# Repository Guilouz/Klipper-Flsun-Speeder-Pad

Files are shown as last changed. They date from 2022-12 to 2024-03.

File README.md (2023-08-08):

 # FLSUN Speeder Pad Configurations

Sans titre-2 copie

<br />

## About

This guide explains the whole process in order to obtain Root access on the Speeder Pad, to configure it correctly with official Klipper builds and optimized printer settings.

By default, FLSUN does not use builds from official GitHub repositories. Updates point to Gitee repositories which are very slow, sometimes inaccessible and not updated.
In addition, during Delta Calibration, tower angles and delta radius are never recalculated in their Klipper build, which can cause several issues.

This settings are compatible with FLSUN Speeder Pad.

- Useful and automated macros with notifications to KlipperScreen
- Improved configurations
- Configurations for many ADXL
- And more...

<br />

Before using Klipper please read this documentations:

- Klipper (Operating System): https://www.klipper3d.org/
- Moonraker (API Web Server): https://moonraker.readthedocs.io/
- Mainsail (Web Interface): https://docs.mainsail.xyz/
- KlipperScreen (Screen Interface): https://klipperscreen.readthedocs.io/

<br />

If you like my work, don't hesitate to support me by paying me a 🍺 or a ☕. Thank you 🙂

Donate (https://ko-fi.com/guilouz)

<br />

## Wiki

Guide is now available here: https://github.com/Guilouz/Klipper-Flsun-Speeder-Pad/wiki

<br />

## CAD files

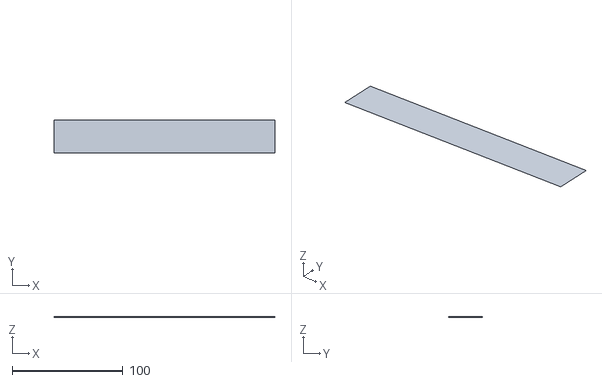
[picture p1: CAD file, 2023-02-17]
Downloads/First_Layer_Test.stl
200.0 x 30.0 x 0.2

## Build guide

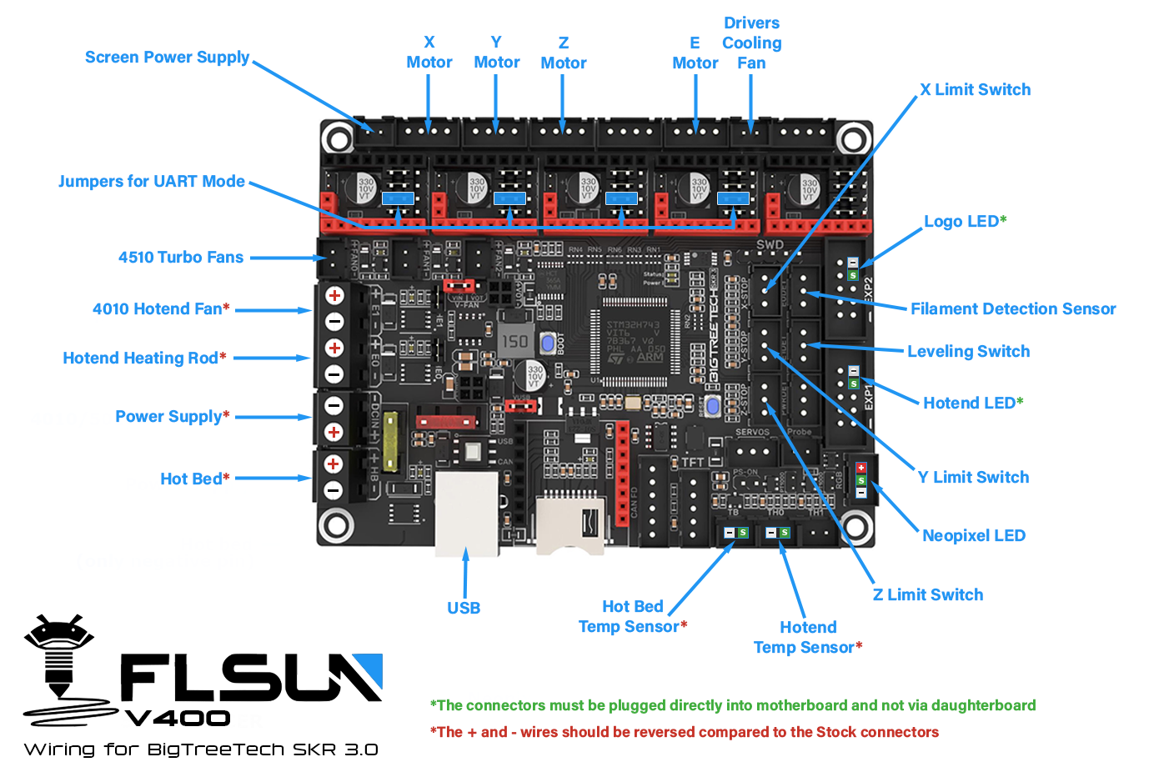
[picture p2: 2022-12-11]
Configurations/FLSUN V400/FLSUN V400 - BigTreeTech SKR 3.0 Wiring.png

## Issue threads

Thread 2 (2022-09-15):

Root via update.sh still work?

arraylabs, 2022-09-15:
I'm not having any luck with the update.sh appearing to do anything. Does this method still work with recently delivered printers/speederpads?

Guilouz, 2022-09-15:
Just fixed this. Re-download zip file.

arraylabs, 2022-09-15:
Thanks, unfortunately it still doesn't appear to do anything. I'm unable to log into the pad with the provided username and password. I also don't see the .over file on the USB after booting the pad with the stick inserted which kinda implies the update.sh script isn't getting run.

Guilouz, 2022-09-15:
Try to re-download new zip, it have been updated to set password for pi user to flsun.

arraylabs, 2022-09-16:
Sorry to say but still no luck. I appreciate your time trying to sort it out.

arraylabs, 2022-09-16:
Just to confirm where the directions say "root folder" that should be the same level as the cura 4 & 5 installation files, correct?

Guilouz, 2022-09-16:
Not understand what you mean with Cura.

Root Acess is needed to change time zone, wifi location, klipper etc in SSH, nothing to see with Cura.

jFensch, 2022-09-16:
I am also experiencing the issue:
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

Guilouz, 2022-09-16:
It seems Flsun have changed something to block root access.

Brubrui, 2022-10-03:
At night, does the password seem to have changed because flsun is not giving access to the spider pad? Do you know anything about it?. thank you

Closed 2022-09-15.

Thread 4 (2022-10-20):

Erreur mise à jour Klipperscreen si multi instances Klipper

ManuMod, 2022-10-20:
Après la modif de moonraker.conf (en PJ), le Hard recovery retourne l'erreur "Repo has not been verified, clone aborted".
[moonraker.conf.txt](https://github.com/Guilouz/Klipper-Flsun-Speeder-Pad/files/9834097/moonraker.conf.txt)

ManuMod, 2022-10-20:
J'ai suivi la procédure avec 3 instances.

Guilouz, 2022-10-20:
Suis la procédure avec une seule instance, il y a des problèmes de compatibilités avec les nouveaux chemins de moonraker changés récemment.

ManuMod, 2022-10-20:
OK, merci pour l'info.
Je voulais conserver la fonctionnalité pour plus tard, mais je peux effectivement débuter Klipper avec 1 instance et refaire une install si je trouve plus stable en multi instances. Tu envisages également de l'utiliser en multi instances ?

Guilouz, 2022-10-20:
Non c’est juste un pad de test, j’en ai un autre avec ma V400

ManuMod, 2022-10-22:
Pour l'info, j'ai eu la même erreur avec 1 seule instance de Klipper, mais qui a été résolu après une mise à jour de Moonraker.

Guilouz, 2022-10-22:
Oui il y a eu des updates aujourd'hui pour Moonraker et notamment un correctif pour le multi instance.

ManuMod, 2022-10-22:
Effectivement, j'ai vu ton issue sur le sujet.
Je ne sais pas s'il y a un rapport avec les màj de Moonraker, mais j'ai également eu 1 erreur avec le service WebcamHD qui restait en état Failed. Ce que j'ai résolu à coup de plugin mainsail/crowsnest.

Guilouz, 2022-10-22:
J’étais pas sûr que crownest fonctionnait correctement sous Ubuntu. Pas de problème avec? La configuration de la cam avec le fichier de conf fonctionne ?

ManuMod, 2022-10-22:
Cela fonctionne tip top avec ma C310. J'ai repris la config par défaut en modifiant seulement la résolution pour 720HD. Aucune erreur à l'install par contre l'ajout auto de l'update n'écrit pas les lignes dans monraker.conf. Faut penser à les ajouter.

Closed 2022-10-20.

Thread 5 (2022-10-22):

Utiliser gcode sur clef USB

ManuMod, 2022-10-22:
Même si l'envoi direct du gcode sur Mainsail est l'utilisation principale, je souhaiterai pouvoir conserver la fonctionnalité de lecture des gcodes sur clef USB.

Le montage de la clef USB n'est pas automatique et une fois montée en SSH, elle n'est pas reconnue dans Mainsaill.

Faut-il mettre en place qq chose du style autofs ou script, associé à un symlink sur 1 dossier dédié dans pi/gcodes_files ?

Guilouz, 2022-10-22:
C’est pas le but de Klipper de print via clé USB ou microSD. C’est bien pour cette raison que ce n’est pas une fonctionnalité de Mainsail.
Il me semble que l’USB est monté uniquement au démarrage si une clé usb est insérée.
Je t’avouerais que je n’ai pas testé, j’envoie tous mes gcode depuis Cura directement sur le pad et ensuite je lance l’impression depuis le pad.

ManuMod, 2022-10-22:
Dsl, effectivement la clef est correctement montée au démarrage et même à chaud, mais dans /pi/gcode_files/USB-Disk alors que Mainsaill utilise /printer_data/gcodes.

Guilouz, 2022-10-22:
Merci de l'info, je vais rajouté ça au tuto.

ManuMod, 2022-10-22:
Je pense qu'il serait plus propre de faire un symlink sur les dossiers gcode uniquement et cela permettrai pour le mode 3 instances (que je compte toujours essayer) de faire un symlink par printer_data sur le même dossier gcodes. Plus simple si une seule et même base de gcode, non?

Guilouz, 2022-10-22:
Oui ça peut être réalisable avec:

ln -s /home/pi/gcode_files/USB-Disk /home/pi/printer_data_1/gcodes/USB-Disk
ln -s /home/pi/gcode_files/USB-Disk /home/pi/printer_data_2/gcodes/USB-Disk
ln -s /home/pi/gcode_files/USB-Disk /home/pi/printer_data_3/gcodes/USB-Disk

J'ai pas encore vraiment poussé les recherches avec plusieurs instances.

ManuMod, 2022-10-22:
Effectivement ce serait LA méthode pour 3 instances.

Ce que j'évoquais était plutôt de limiter le symlink au /home/pi/gcode_files/, mais après mûre réflexion (ou plutôt 1 peu de repos ;-), c'est une bêtise pour les 3 instances, au vue des config dédiées aux imprimantes et/ou PLA.

Guilouz, 2022-10-22:
Oui car chaque imprimante est différente et n’utilisent pas forcément toutes les mêmes gcodes.
Il est préférable d’avoir pour chacunes d’elles leurs dossiers gcode.

Closed 2022-10-22.

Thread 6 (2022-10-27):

Timelapse pour 3 instances de Klipper

ManuMod, 2022-10-27:
Salut,

L'installateur de Timelapse ne gère pas le multi-instance de Klipper. Du coup, cela se passe manuellement sous SSH. source https://github.com/mainsail-crew/moonraker-timelapse/issues/13

Exemple pour 3 instances de Klipper :

```
cd ~/
git clone https://github.com/mainsail-crew/moonraker-timelapse.git
ln -sf "/home/pi/moonraker-timelapse/component/timelapse.py" "/home/pi/moonraker/moonraker/components/timelapse.py"
ln -sf "/home/pi/moonraker-timelapse/klipper_macro/timelapse.cfg" "/home/pi/printer_1_data/config/timelapse.cfg"
ln -sf "/home/pi/moonraker-timelapse/klipper_macro/timelapse.cfg" "/home/pi/printer_2_data/config/timelapse.cfg"
ln -sf "/home/pi/moonraker-timelapse/klipper_macro/timelapse.cfg" "/home/pi/printer_3_data/config/timelapse.cfg"
sudo reboot
```

:warning: Ne pas oublier d'ajouter [timelapse] dans le fichier Moonraker.conf, ainsi que les lignes pour l'update.

Si le service WebcamHD ne fonctionne pas (comme moi :smile:) , possible d’utiliser le plugin de Mainsall : https://github.com/mainsail-crew/crowsnest

Guilouz, 2022-10-27:
Bien vu, j'utilise pas les timelapse alors je me suis pas penché dessus.

Guilouz, 2022-10-27:
J'ai déjà reporté l'issue ici : https://github.com/mainsail-crew/moonraker-timelapse/issues/71

Closed 2022-10-27.

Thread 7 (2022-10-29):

Keyboard missing some typo ...

themacboy, 2022-10-29:
After update the board I tryed to connect to my network but ... when I type my passwords I can't set some symbol.

Thats symbol is used on my network pass, and I can't change it due I had more than 30 perophericals connected to this network.

Any idea?

themacboy, 2022-10-29:
Finally I just connected a external keyboard.

Closed 2022-10-29.

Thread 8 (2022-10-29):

ADXL345 issue ...

themacboy, 2022-10-29:
Excuse me, I doubt this is a problem with your config. But I will try to ask for help.

After running the TEST_RESONANCES AXIS=X, I get always this error:

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

Any idea? Is this speeder pad to weak?

themacboy, 2022-10-29:
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

Ummm xorg? why is this process running and having too much CPU load? lol

themacboy, 2022-10-29:
I just used:

sudo service KlipperScreen stop

to stop Xorg, but the problem still happens!

themacboy, 2022-10-29:
Solved !

I have reduced microsteps from 128 to 32.

Too much data load to run a resonance test !

Guilouz, 2022-10-29:
Working fine for me with 128 microsteps. I have doing many tests for that without issue.

themacboy, 2022-10-30:
Can you share the actual specs of your Speeder Pad? I like to compare with mine to check for different hardware versions.

Thanks in advance!

Guilouz, 2022-10-30:
description: Computer
    product: sun50iw10
    width: 32 bits
    capabilities: smp
  *-core
       description: Motherboard
       physical id: 0
     *-cpu:0
          description: CPU
          product: cpu
          physical id: 0
          bus info: cpu@0
          size: 1512MHz
          capacity: 1512MHz
          capabilities: fp asimd aes pmull sha1 sha2 crc32 cpufreq
     *-cpu:1
          description: CPU
          product: cpu
          physical id: 1
          bus info: cpu@1
          size: 1512MHz
          capacity: 1512MHz
          capabilities: fp asimd aes pmull sha1 sha2 crc32 cpufreq
     *-cpu:2
          description: CPU
          product: cpu
          physical id: 2
          bus info: cpu@2
          size: 1512MHz
          capacity: 1512MHz
          capabilities: fp asimd aes pmull sha1 sha2 crc32 cpufreq
     *-cpu:3
          description: CPU
          product: cpu
          physical id: 3
          bus info: cpu@3
          size: 1512MHz
          capacity: 1512MHz
          capabilities: fp asimd aes pmull sha1 sha2 crc32 cpufreq
     *-cpu:4 DISABLED
          description: CPU
          product: idle-states
          physical id: 4
          bus info: cpu@4
     *-memory
          description: System memory
          physical id: 5
          size: 976MiB
  *-usbhost:0
       product: SW USB2.0 'Enhanced' Host Controller (EHCI) Driver
       vendor: Linux 4.9.191 ehci_hcd
       physical id: 1
       bus info: usb@1
       logical name: usb1
       version: 4.09
       capabilities: usb-2.00
       configuration: driver=hub slots=1 speed=480Mbit/s
     *-usb
          description: USB hub
          product: USB2.0 Hub
          vendor: Genesys Logic, Inc.
          physical id: 1
          bus info: usb@1:1
          version: 85.38
          capabilities: usb-2.00
          configuration: driver=hub maxpower=100mA slots=4 speed=480Mbit/s
        *-usb
             description: USB hub
             product: USB2.0 Hub
             vendor: Genesys Logic, Inc.
             physical id: 1
             bus info: usb@1:1.1
             version: 85.38
             capabilities: usb-2.00
             configuration: driver=hub maxpower=100mA slots=4 speed=480Mbit/s
           *-usb
                description: Generic USB device
                product: USB 10/100 LAN
                vendor: Realtek
                physical id: 2
                bus info: usb@1:1.1.2
                version: 20.00
                serial: 000000000000
                capabilities: usb-2.10
                configuration: driver=r8152 maxpower=100mA speed=480Mbit/s
  *-usbhost:1
       product: SW USB2.0 'Open' Host Controller (OHCI) Driver
       vendor: Linux 4.9.191 ohci_hcd
       physical id: 2
       bus info: usb@2
       logical name: usb2
       version: 4.09
       capabilities: usb-1.10
       configuration: driver=hub slots=1 speed=12Mbit/s
  *-mmc0
       description: MMC Host
       physical id: 3
       logical name: mmc0
     *-device
          description: SD/MMC Device
          product: AJTD4R
          vendor: Unknown (21)
          physical id: 0
          logical name: /dev/mmcblk0
          date: 07/2022
          serial: 4152223877
          size: 15634268160
          capabilities: mmc gpt-1.00 partitioned partitioned:gpt
          configuration: guid=ab6f3888-569a-4926-9668-80941dcb40bc logicalsectorsize=512 sectorsize=512
        *-volume:0
             description: Windows FAT volume
             physical id: 1
             logical name: /dev/mmcblk0p1
             version: FAT16
             serial: 0000-0000
             size: 15EiB
             capabilities: nomount fat initialized
             configuration: FATs=2 filesystem=fat label=Volumn name=boot-resource
        *-volume:1
             description: data partition
             vendor: Windows
             physical id: 2
             logical name: /dev/mmcblk0p2
             serial: a0085546-4166-744a-a353-fca9272b8e46
             capacity: 511KiB
             capabilities: nomount
             configuration: name=env
        *-volume:2
             description: data partition
             vendor: Windows
             physical id: 3
             logical name: /dev/mmcblk0p3
             serial: a0085546-4166-744a-a353-fca9272b8e47
             capacity: 511KiB
             capabilities: nomount
             configuration: name=env-redund
        *-volume:3
             description: data partition
             vendor: Windows
             physical id: 4
             logical name: /dev/mmcblk0p4
             serial: a0085546-4166-744a-a353-fca9272b8e48
             capacity: 14MiB
             capabilities: nomount
             configuration: name=boot
        *-volume:4
             description: EXT4 volume
             vendor: Linux
             physical id: 5
             logical name: /dev/mmcblk0p5
             version: 1.0
             serial: dff38665-5375-4b5a-b230-cb6e7966bc49
             size: 14GiB
             capacity: 14GiB
             capabilities: nomount journaled extended_attributes large_files huge_files dir_nlink recover 64bit extents ext4 ext2 initialized
             configuration: created=2022-09-09 05:32:23 filesystem=ext4 label=rootfs lastmountpoint=/ modified=1970-01-01 01:00:07 mounted=1970-01-01 01:00:07 name=rootfs state=clean
        *-volume:5
             description: data partition
             vendor: Windows
             physical id: 6
             logical name: /dev/mmcblk0p6
             serial: a0085546-4166-744a-a353-fca9272b8e4a
             capacity: 4095KiB
             capabilities: nomount
             configuration: name=rootfs_data
        *-volume:6
             description: data partition
             vendor: Windows
             physical id: 7
             logical name: /dev/mmcblk0p7
             serial: a0085546-4166-744a-a353-fca9272b8e4b
             capacity: 511KiB
             capabilities: nomount
             configuration: name=private
        *-volume:7
             description: data partition
             vendor: Windows
             physical id: 8
             logical name: /dev/mmcblk0p8
             serial: a0085546-4166-744a-a353-fca9272b8e4c
             capacity: 15MiB
             capabilities: nomount
             configuration: name=recovery
        *-volume:8
             description: data partition
             vendor: Windows
             physical id: 9
             logical name: /dev/mmcblk0p9
             serial: a0085546-4166-744a-a353-fca9272b8e4d
             capacity: 511KiB
             capabilities: nomount
             configuration: name=UDISK
  *-mmc1
       description: MMC Host
       physical id: 4
       logical name: mmc1
  *-mmc2
       description: MMC Host
       physical id: 5
       logical name: mmc2
     *-device
          description: SDIO Device
          physical id: 0
          bus info: mmc@2:0001
          serial: 0
          capabilities: sdio
        *-interface:0
             product: 43430
             vendor: Broadcom
             physical id: 1
             bus info: mmc@2:0001:1
             logical name: mmc2:0001:1
        *-interface:1
             product: 43430
             vendor: Broadcom
             physical id: 2
             bus info: mmc@2:0001:2
             logical name: mmc2:0001:2
  *-sound
       description: audiocodec
       physical id: 6
       logical name: card0
       logical name: /dev/snd/controlC0
       logical name: /dev/snd/pcmC0D0c
       logical name: /dev/snd/pcmC0D0p
  *-graphics
       physical id: 7
       logical name: /dev/fb0
       capabilities: fb
       configuration: depth=32 resolution=1024,600
  *-input:0
       product: sunxi-keyboard
       physical id: 8
       logical name: input0
       logical name: /dev/input/event0
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
themacboy, 2022-10-31:
Looks similar :( hahaha

Thx

fzechert, 2022-11-08:
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

Thanks, this worked for me as well, I used 64 microsteps in the configuration file.
After the calibration is done, I can set microsteps back to 128 right? Only a problem during the calibration.

Guilouz, 2022-11-08:
I have no issue with adxl and 128 microsteps.
No you must use settings you have used while Resonance testing

themacboy, 2022-11-08:
> I have no issue with adxl and 128 microsteps. No you must use settings you have used while Resonance testing

listen people! ;) lot of them having this issue while doing resonance check or while printing too.

Guilouz, 2022-11-08:
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

I have 2 pad, one V400 pad on Ubuntu 20.04 LTS and one standalone pad on Ubuntu 22.04 LTS, I tested them both with resonance tests up to 130 Hz without problem (with rpi pico and pis module) and printed an object older than 17h.

I don't understand what's affecting this in both of you but it works well in other people as well.
However nothing prevents you from using 16 microsteps if you want ;) More steps potentially means a more precise machine.

themacboy, 2022-11-08:
> I don't understand what's affecting this in both of you but it works well in other people as well. However nothing prevents you from using 16 microsteps if you want ;) More steps potentially means a more precise machine.

I don't understand it either.

I personally lowered it to 32, and now it works fine.
Really, just a 3D printer we don't need this high precision and loss of torque

fzechert, 2022-11-09:
Thanks for your help and hints. Here is my solution that I managed to get working (kind of). If somebody stumbles upon this issue in the future, it might help.

Unfortunately, I did not have another Microcontroller that is compatible with Klipper other than the PI Zero. So my solution now was to set up Klipper completely on a Raspberry PI 4B 4GB, and not using the Speeder Pad from FLSUN.

This makes it possible to connect the ADXL to the GPIO PINs of the Raspberry PI directly, without the need of an intermediate Pi Zero. Configuration for this can be found in the Klipper Manual: https://www.klipper3d.org/Measuring_Resonances.html and https://www.klipper3d.org/RPi_microcontroller.html

Even with the Raspberry PI 4B 4GB I was not able to complete the SAHPER_CALIBRATE command successfully. It worked for the X Axis but the Y Axis failed at 124 Hz (with 128 micro steps). But since the test normally ends at 133 Hz, which is not so far from 124 Hz, I figured this is good enough.

So I ran the following commands in Klipper:

```
SHAPER_CALIBRATE AXIS=x
SHAPER_CALIBRATE AXIS=y FREQ_END=123
```

This worked fine and I got the following results:

```
[input_shaper]
shaper_type_x = mzv
shaper_freq_x = 53.4
shaper_type_y = mzv
shaper_freq_y = 56.2
```

Then I disconnected the Raspberry PI and connected again with the Speeder Pad. Just Copy those configurations to the `printer.cfg` in the SpeedPad, and done.

I still don't know why we have so many problems with the input shaper. But this is good enough for me now.

If anybody has an Idea on how to trouble shoot this further and find / fix the underlying problem, let me know. I will be glad to help in troubleshooting. But until then, I am out of ideas as well.

:smile:

Closed 2022-10-29.

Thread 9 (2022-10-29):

Web Cam not working

Naninani, 2022-10-29:
Thx for putting together this guide! I just got my v400 and update it using your repo.

The issue with the web cam is that it is not initialized. It was working perfectly fine with the stock pad and firmware, but stopped after the update.

Some findings.
1. `usbutils` is not installed by default. I had to install it in order to list the attached devices.
    ```
     $ lsusb
     -bash: lsusb: command not found
    ```

    ```
    $ sudo apt-get install usbutils
    ```

1. `lsusb` shows the camera and it recognized by the system.
    ```
    $ lsusb
    Bus 002 Device 001: ID 1d6b:0001 Linux Foundation 1.1 root hub
    Bus 001 Device 004: ID 1a86:7523 QinHeng Electronics HL-340 USB-Serial adapter
    Bus 001 Device 006: ID 046d:0843 Logitech, Inc. Webcam C930e
    Bus 001 Device 005: ID 0bda:8152 Realtek Semiconductor Corp. RTL8152 Fast Ethernet Adapter
    Bus 001 Device 003: ID 05e3:0608 Genesys Logic, Inc. Hub
    Bus 001 Device 002: ID 05e3:0608 Genesys Logic, Inc. Hub
    Bus 001 Device 001: ID 1d6b:0002 Linux Foundation 2.0 root hub
    ```

1. However its not initialized
    ```
    $ dmesg | grep -i "Camera"
    [   11.303638] uvcvideo 1-1.3:1.0: Entity type for entity Camera 1 was not initialized!
    [  360.264708] uvcvideo 1-1.3:1.0: Entity type for entity Camera 1 was not initialized!
    ```

    ```
    $ ls -ltrh /dev/video*
    crw-rw---- 1 root video 81, 0 Oct 29 02:32 /dev/video0
    ```

    ```
    sudo lsusb -t
    /:  Bus 02.Port 1: Dev 1, Class=root_hub, Driver=sunxi-ohci/1p, 12M
    /:  Bus 01.Port 1: Dev 1, Class=root_hub, Driver=sunxi-ehci/1p, 480M
        |__ Port 1: Dev 2, If 0, Class=Hub, Driver=hub/4p, 480M
            |__ Port 1: Dev 3, If 0, Class=Hub, Driver=hub/4p, 480M
                |__ Port 2: Dev 5, If 0, Class=Vendor Specific Class, Driver=r8152, 480M
            |__ Port 3: Dev 4, If 0, Class=Video, Driver=uvcvideo, 480M
            |__ Port 3: Dev 4, If 1, Class=Video, Driver=uvcvideo, 480M
            |__ Port 3: Dev 4, If 2, Class=Audio, Driver=, 480M
            |__ Port 3: Dev 4, If 3, Class=Audio, Driver=, 480M
            |__ Port 4: Dev 6, If 0, Class=Vendor Specific Class, Driver=ch341, 12M
    ```

Guilouz, 2022-10-29:
Check my github to use Crowsnest

Closed 2022-10-29.

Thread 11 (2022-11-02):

Update docs

piwi3910, 2022-11-02:
Please update the docs, to reflect the V400 motherboard needs a max 8GB sdcard, with bigger ones, you will not be able to format it correctly.

themacboy, 2022-11-02:
Are you sure? I only own 16gb micro sd cards, and remember that I have updated my MKS Robin nano V.2 a few times.

But not totally sure now.

piwi3910, 2022-11-02:
I'm sure a 32GB doesn't work, tried multiple
Tried it with a 4 and 8 an both work. 16 I didn't try as I didn't have any

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

Guilouz, 2022-11-03:
I can flash my V400 with my 16Gb or 32Gb microSD without issue.

fzechert, 2022-11-06:
I can confirm this issue with my V400 printer. Flashing the SpeederPad worked with 32GB / 64GB micro SD card. Flashing the Robin_nano35.bin firmware to the board installed in the top of the printer did not work with 32GB / 64GB micro SD card. I had an old 64MB SD-Card with a SD to micro SD adapter that worked fine.

Maybe just add a hint, if the flashing does not work, use a <= 16GB SD Card.

Anyway, thanks for this great manual and your effort @Guilouz

Closed 2022-11-03.

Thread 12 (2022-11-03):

crowsnest install docs incomplete

piwi3910, 2022-11-03:
There are some steps missing for crowsnest

1) the default crowsnest service looks for the config file at /home/pi/klipper_config/crowsnest.conf
This means that the template that you copy over in your step:

"cp /home/pi/crowsnest/sample_configs/mainsail_default.conf /home/pi/printer_data/config/crowsnest.conf"
is not loaded

as you can see from this log:

[11/03/22 08:43:33] crowsnest: Version Control: ffmpeg is up to date. (4.2.7-0ubuntu0.1)
[11/03/22 08:43:33] crowsnest: INFO: Print Configfile: '/home/pi/klipper_config/crowsnest.conf'
[11/03/22 08:43:33] crowsnest:          [crowsnest]
[11/03/22 08:43:33] crowsnest:          log_path: ~/klipper_logs/crowsnest.log
[11/03/22 08:43:33] crowsnest:          log_level: verbose
[11/03/22 08:43:33] crowsnest:          delete_log: false
[11/03/22 08:43:33] crowsnest:
[11/03/22 08:43:33] crowsnest:          [cam 1]
[11/03/22 08:43:33] crowsnest:          mode: mjpg
[11/03/22 08:43:33] crowsnest:          port: 8080
[11/03/22 08:43:34] crowsnest:          device: /dev/video0
[11/03/22 08:43:34] crowsnest:          resolution: 640x480
[11/03/22 08:43:34] crowsnest:          max_fps: 15

the fix is:

sudo nano /etc/systemd/system/crowsnest.service
 change the line Environment to reflect the right path
Environment=CROWSNEST_CONFIG=/home/pi/printer_data/config/crowsnest.conf
systemctl daemon-reload
and restart your crowsnest service from mainsail or systemd
rm -rf /home/pi/klipper_config

then logs show correct:

[11/03/22 08:47:44] crowsnest: Version Control: ffmpeg is up to date. (4.2.7-0ubuntu0.1)
[11/03/22 08:47:44] crowsnest: INFO: Print Configfile: '/home/pi/printer_data/config/crowsnest.conf'
[11/03/22 08:47:44] crowsnest:          [crowsnest]
[11/03/22 08:47:44] crowsnest:          log_path: ~/klipper_logs/crowsnest.log
[11/03/22 08:47:44] crowsnest:          log_level: verbose
[11/03/22 08:47:44] crowsnest:          delete_log: false
[11/03/22 08:47:44] crowsnest:
[11/03/22 08:47:44] crowsnest:          [cam 1]
[11/03/22 08:47:44] crowsnest:          mode: mjpg
[11/03/22 08:47:44] crowsnest:          port: 8080
[11/03/22 08:47:44] crowsnest:          device: /dev/video0
[11/03/22 08:47:44] crowsnest:          resolution: 1920x1080
[11/03/22 08:47:44] crowsnest:          max_fps: 25
[11/03/22 08:47:44] crowsnest:          v4l2ctl: focus_auto=0,focus_absolute=50,zoom_absolute=100,exposure_auto_priority=0,exposure_auto=1,exposure_absolute=500,brightness=150,contrast=128,saturation=128,sharpness=128,white_balance_temperature_auto=0,white_balance_temperature=3250

now if you run 3 instances: copying over the template file 3 times doesn't seem to work well.
as crowsnest only runs once, and takes all camera's it can find.
So it would be better to copy it once, configure all your camera's in the config of instance 1
and then in the other instances select the right cam

Guilouz, 2022-11-03:
There is also a new branch for crownest but I have not tested it : https://github.com/mainsail-crew/crowsnest/tree/ref/installer

piwi3910, 2022-11-03:
yes looking at the commits, they are planning on taking the changes i mentioned, and make them configurable during make install, but until that moment you will have to the changes manually for now.
crowsnest is actually really good. the v42ctl integration is great and allows you to control things like autofocus

Guilouz, 2022-11-03:
Just updated doc with new Crowsnest.

Closed 2022-11-03.

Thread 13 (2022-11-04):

[BUG] Unable to install Klipper Screen - Error building numpy wheels

cottec, 2022-11-04:
during installation of Klipper Screen ./scripts/KlipperScreen-install.sh
it's stopping with an error:

Building wheels for collected packages: numpy
  Building wheel for numpy (PEP 517) ... error
  ERROR: Failed building wheel for numpy
Failed to build numpy
ERROR: Could not build wheels for numpy which use PEP 517 and cannot be installed directly
Error: pip install exited with status code 0
Unable to install dependencies, aborting install.

did anyone already experience that and can support?

full log file:
[numpy4.txt](https://github.com/Guilouz/Klipper-Flsun-Speeder-Pad/files/9940386/numpy4.txt)

Guilouz, 2022-11-05:
Already reported, it's not related to my KlipperScreen version, same issue with official build.

Closed 2022-11-05.

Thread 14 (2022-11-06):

Neopixel link

VeNOm696, 2022-11-06:
Many Thanks! real nice.. your guide helped me a lot.
Just one thing. I think the neo pixel ali express link is wrong.
In your link are WS2813 i think WS2812 are the right ones

best wishes!

Guilouz, 2022-11-06:
WS2813 works fine. From the moment there are controllable LEDs, no problem

Closed 2022-11-06.

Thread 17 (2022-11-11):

timelapse indique DETACHED

gigis57, 2022-11-11:
Bonjour,

J'ai installé par 2x la pad (3 instances) et quand j'arrive à l'installation TIMELAPSE, j'ai sur mainsail -> timelapse indique DETACHED et même le rafraichissement ne fonctionne pas et ni soft ni hard recovery.

Qu'est-il possible de faire ? Merci

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

Guilouz, 2022-11-11:
Est-ce que tu as redémarré entre temps ?

gigis57, 2022-11-11:
oui j'ai redemarré entre chaque étape demandé. et comme dis plus je fais et refais l'installation 2x de suite car la 1ière je pensais avoir oublié un truc mais j'ai copié/collé 1 à 1 les étapes décrites. (3 instances)

gigis57, 2022-11-13:
Bien apparemment, je l'ai résolu en supprimant manuellement le dossier timelapse et en le réinstallant. Je poursuis les étapes suivantes. Merci

Closed 2022-11-13.

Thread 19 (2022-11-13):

message d'erreur: crowsnest.conf could not be uploaded!

gigis57, 2022-11-13:
Bonjour,

Après avoir résolu le probleme avec l'installation TIMELAPSE, j'ai maintenant un probleme avec l'initialisation de la webcam et de crowsnest.

Impossible de faire reconnaitre la webcam MAINSAL et/ou crowsnest. Et dès que que je veux enregister le fichier conf, j'ai le message d'erreur suivant :  crowsnest.conf could not be uploaded!

Dans MobaXterm; Bus 001 .... Realtek Semiconductor Corp. (quelques soit la marque et j'ai essayé plusiers webcam différentes).
J'ai une installation 3 instances, Speeder Pad connecté à ma SR et webcam branchée sur le 4ieme port (celui qui est caché d'origine) mais j'ai aussi essayé sur les autres ports usb "visible".

Les webcams fonctionnent très bien avec l'image d'origine avant modification (et meme sur le port 4).

Merci

Closed 2022-11-18.

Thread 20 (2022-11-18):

Klipper not loading after Enable Root Access

ArikMerzon1, 2022-11-18:
I've followed all the steps of the `Enable Root Access` guide twice with the same outcome.

```
Klipper has encountered an error.
Issue a FIRMWARE RESTART to attempt fixing the issue.

mcu 'mcu': Unable to connect
Once the underlying issue is corrected, use the
"FIRMWARE RESTART" command to reset the firmware, reload the config, and restart the host software.

```
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

Guilouz, 2022-11-18:
You must not have followed all the steps because I see that you still have the version of KlipperScreen from Flsun.

Closed 2022-11-18.

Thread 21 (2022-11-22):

Extruder doesn't work

ArikMerzon1, 2022-11-22:
I've followed through with the tutorial and everything seems to be fine.
I did all the calibrations.
Started a new print and although the print head is moving the extruder doesn't work.
I've tried to extrude manually and it's the same thing no extrusion and no errors in the console.
I checked the cables and they are fine.

I can provide more data

*as a side note, the extruder was working

Guilouz, 2022-11-22:
which printer?

ArikMerzon1, 2022-11-22:
Speed Racer with a Nano V3 board

Guilouz, 2022-11-22:
Do you use the correct printer.cfg file for it?

ArikMerzon1, 2022-11-22:
I've uploaded the `printer.cfg` with the rest of the Configurations files
But now I see that I have multiple printer-####_####.cfg files
Is it correct?

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

Guilouz, 2022-11-22:
Stock folder?

Yes it’s normal it’s backup files.

ArikMerzon1, 2022-11-22:
you mean this `/Klipper-Flsun-Speeder-Pad-main/Configurations/FLSUN Super Racer/Robin Nano 3.0-3.1 - LGX Lite`

Guilouz, 2022-11-22:
Do you have LGX Lite extruder ?

ArikMerzon1, 2022-11-22:
sorry, my bad it's stock extruder
this is my `printer.cfg`
`#   _____             __ _                       _   _        
#  / ____|           / _(_)                     | | (_)        
# | |     ___  _ __ | |_ _  __ _ _   _ _ __ __ _| |_ _  ___  _ __  ___
# | |    / _ \| '_ \|  _| |/ _` | | | | '__/ _` | __| |/ _ \| '_ \/ __|
# | |___| (_) | | | | | | | (_| | |_| | | | (_| | |_| | (_) | | | \__ \
#  \_____\___/|_| |_|_| |_|\__, |\__,_|_|  \__,_|\__|_|\___/|_| |_|___/
#                           __/ |                              
#                          |___/
#
# Klipper Configurations - Flsun Super Racer
#
# Guislain Cyril

# MKS Robin Nano V3.0/V3.1
# When running "make menuconfig"
#
# [*] Enable extra low-level configuration options
#     Micro-controller Architecture (STMicroelectronics STM32)  --->
#     Processor model (STM32F407)  --->
#     Bootloader offset (48KiB bootloader (MKS Robin Nano V3))  --->
#     Clock Reference (8 MHz crystal)  --->
#     Communication interface (USB (on PA11/PA12))  --->
# (250000) Baud rate for serial port
# ()  GPIO pins to set at micro-controller startup (NEW)
#
# Note that the "make flash" command does not work with this board.
# Rename the file out/klipper.bin to Robin_nano_v3.bin, copy it an microSD
# card, insert it in the printer and restart it.

########################################
# Editable Settings
########################################

# Notes: Some settings can be enabled or disabled by removing or adding the '#' symbol
#
# PID (pid_Kp, pid_Ki, pid_Kd) --> [extruder] and [heater_bed] sections
# E-Steps Extruder (rotation_distance) --> [extruder] section --> full_steps_per_rotation * microsteps / steps_per_mm = rotation_distance
# Pressure Advance (pressure_advance) --> [extruder] section -- See: https://www.klipper3d.org/Pressure_Advance.html
# Firmware Retraction --> [firmware_retraction] section -- Requires "Klipper Settings Plugin" for Cura -- See: https://github.com/jjgraphix/KlipperSettingsPlugin
# ADXL345 function for resonance testing --> Enable/Disable [include adxl345_pico.cfg] or [include adxl345_fysetc.cfg] -- Configuration in [input_shaper] section -- See: https://www.klipper3d.org/Measuring_Resonances.html
# NeoPixels function --> Enable/Disable [include neopixels.cfg]
# Timelapse function --> Enable/Disable [include timelapse.cfg]

########################################
# Included Files
########################################

[include macros.cfg]
#[include adxl345_pico.cfg]  #Enable if you want to use ADXL with Rapsberry Pi Pico
#[include adxl345_fysetc.cfg]  #Enable if you want to use ADXL with Fysetc Portable Input Shaper
#[include timelapse.cfg]  #Enable if you want to use Timelapse
#[include neopixels.cfg]  #Enable if you want to use Neopixels

########################################
# Printer Settings
########################################

[printer]
kinematics: delta
max_velocity: 300
max_accel: 4000
max_accel_to_decel: 2000
square_corner_velocity: 5
max_z_velocity: 300
print_radius: 132
minimum_z_position= -5
#delta_radius: 151.7

########################################
# X Stepper Motor & Driver Settings
########################################

[stepper_a]
step_pin: PE3
dir_pin: PE2
enable_pin: !PE4
microsteps: 16
rotation_distance: 40
endstop_pin: PA15
homing_speed: 50
homing_retract_dist: 5.0
homing_retract_speed: 10
#angle: 210
#position_endstop: 336
#arm_length = 315

[tmc2209 stepper_a]
uart_pin: PD5
run_current: 1.138
hold_current: 0.5
stealthchop_threshold: 999999

########################################
# Y Stepper Motor & Driver Settings
########################################

[stepper_b]
step_pin: PE0
dir_pin: PB9
enable_pin: !PE1
microsteps: 16
rotation_distance: 40
endstop_pin: PD2
#angle: 330

[tmc2209 stepper_b]
uart_pin: PD7
run_current: 1.138
hold_current: 0.5
stealthchop_threshold: 999999

########################################
# Z Stepper Motor & Driver Settings
########################################

[stepper_c]
step_pin: PB5
dir_pin: PB4
enable_pin: !PB8
microsteps: 16
rotation_distance: 40
endstop_pin: PC4
#angle: 90

[tmc2209 stepper_c]
uart_pin: PD4
run_current: 1.138
hold_current: 0.5
stealthchop_threshold: 999999

########################################
# Extruder & Driver Settings
########################################

[extruder]
step_pin: PD6
dir_pin: !PD3
enable_pin: !PB3
microsteps: 16
rotation_distance: 7.805
nozzle_diameter: 0.4
filament_diameter: 1.750
heater_pin: PE5
sensor_type: EPCOS 100K B57560G104F
sensor_pin: PC1
min_temp: -5
max_temp: 275
max_extrude_cross_section: 110
max_extrude_only_distance: 1100
#pressure_advance: 0.04
#pressure_advance_smooth_time: 0.01
control = pid
pid_kp = 18.240
pid_ki = 0.558
pid_kd = 149.109

[tmc2209 extruder]
uart_pin: PD9
run_current: 1.1
hold_current: 0.5
stealthchop_threshold: 999999

########################################
# Bed Settings
########################################

[heater_bed]
heater_pin: PA0
sensor_type: EPCOS 100K B57560G104F
sensor_pin: PC0
min_temp: -5
max_temp: 115
control = pid
pid_kp = 71.041
pid_ki = 1.422
pid_kd = 887.123

########################################
# Filament Sensor Settings
########################################

[filament_switch_sensor filament_sensor]
pause_on_runout: True
runout_gcode: M600
switch_pin: PA4

########################################
# Fans Settings
########################################

[fan]
pin: PC14

[heater_fan Hotend]
pin: PB0
heater_temp: 50.0

########################################
# Probe Settings
########################################

[probe]
pin: !PC8
x_offset: 0
y_offset: 0
#z_offset: 16.85
speed: 10
samples: 3
samples_result: average
sample_retract_dist: 3
samples_tolerance: 0.02
samples_tolerance_retries: 5

########################################
# Delta Calibration & Mesh Settings
########################################

[delta_calibrate]
radius: 130
horizontal_move_z: 25
Speed: 100

[bed_mesh]
speed: 80
horizontal_move_z: 25
mesh_radius: 130
mesh_origin: 0,0
mesh_pps: 5,5
round_probe_count: 5
algorithm: bicubic
bicubic_tension: 0.1
move_check_distance: 3
#fade_start: 1
#fade_end: 30

########################################
# Temperature Controls
########################################

[verify_heater extruder]
max_error: 500
hysteresis: 20

[verify_heater heater_bed]
max_error: 120
hysteresis: 5

########################################
# Firmware Retraction Settings
########################################

[firmware_retraction]
retract_length: 1.2
retract_speed: 35
unretract_extra_length: 0.05
unretract_speed: 35

########################################
# Input Shaper Settings
########################################

[input_shaper]
shaper_freq_x: 25.00
shaper_type_x = mzv
shaper_freq_y: 23.29
shaper_type_y = mzv

########################################
# G-Code Macros & Events
########################################

[idle_timeout]
timeout: 1800

[save_variables]
filename: ~/printer_data/config/variables.cfg

[gcode_arcs]

[pause_resume]

[display_status]

[respond]

[exclude_object]

[virtual_sdcard]
path: ~/printer_data/gcodes

[endstop_phase stepper_a]
endstop_align_zero: false

[endstop_phase stepper_b]
endstop_align_zero: false

[endstop_phase stepper_c]
endstop_align_zero: false

########################################
# MCU Settings
########################################

[mcu]
serial: /dev/serial/by-id/usb-Klipper_stm32f407xx_3A004F000D50414238323520-if00
restart_method: command

[temperature_sensor Speeder_Pad]
sensor_type: temperature_host
min_temp: 10
max_temp: 100

[temperature_sensor Motherboard]
sensor_type: temperature_mcu
min_temp: 0
max_temp: 100

########################################
# LED Settings
########################################

[neopixel RGB]
pin: PB2
chain_count: 34
color_order: GRB
initial_RED: 0.0
initial_GREEN: 0.0
initial_BLUE: 0.0

#*# <---------------------- SAVE_CONFIG ---------------------->
#*# DO NOT EDIT THIS BLOCK OR BELOW. The contents are auto-generated.
#*#
#*# [bed_mesh default]
#*# version = 1
#*# points =
#*# 	-1.862008, -1.862008, -1.862008, -1.862008, -1.862008
#*# 	-2.241428, -2.241428, -1.937405, -1.770595, -1.770595
#*# 	-2.149645, -2.005184, -1.704167, -1.492684, -1.362145
#*# 	-1.551624, -1.551624, -1.264554, -1.043291, -1.043291
#*# 	-0.873923, -0.873923, -0.873923, -0.873923, -0.873923
#*# tension = 0.1
#*# min_x = -130.01
#*# algo = bicubic
#*# y_count = 5
#*# mesh_y_pps = 5
#*# min_y = -130.0
#*# x_count = 5
#*# max_y = 130.0
#*# mesh_x_pps = 5
#*# max_x = 130.01
#*#
#*# [printer]
#*# delta_radius = 151.918026
#*#
#*# [stepper_a]
#*# angle = 210.297779
#*# arm_length = 315.000000
#*# position_endstop = 338.526098
#*#
#*# [stepper_b]
#*# angle = 329.977355
#*# arm_length = 315.000000
#*# position_endstop = 337.745403
#*#
#*# [stepper_c]
#*# angle = 90.000000
#*# arm_length = 315.000000
#*# position_endstop = 336.783223
#*#
#*# [delta_calibrate]
#*# height0 = 16.85
#*# height0_pos = 25668.333,25668.333,25668.333
#*# height1 = 16.85
#*# height1_pos = 31248.333,31248.333,22588.333
#*# height2 = 16.85
#*# height2_pos = 25087.000,34601.000,25087.000
#*# height3 = 16.85
#*# height3_pos = 22820.333,30416.333,30416.333
#*# height4 = 16.85
#*# height4_pos = 24903.333,24903.333,31711.000
#*# height5 = 16.85
#*# height5_pos = 29525.667,22929.333,29525.667
#*# height6 = 16.85
#*# height6_pos = 32986.667,24910.667,24910.667
#*#
#*# [probe]
#*# z_offset = 15.550
#*#
#*# [endstop_phase stepper_a]
#*# trigger_phase = 45/64
#*#
#*# [endstop_phase stepper_b]
#*# trigger_phase = 55/64
#*#
#*# [endstop_phase stepper_c]
#*# trigger_phase = 60/64
`

ArikMerzon1, 2022-11-22:
and i did use the right folder `/Klipper-Flsun-Speeder-Pad-main/Configurations/FLSUN Super Racer/Robin Nano 3.0-3.1 - Stock`

ArikMerzon1, 2022-11-23:
Redid all the steps once again and it's working.
Probably I've missed something along the way.

@Guilouz One question though, is there a way (config) to turn off the small screen of the SR?

Guilouz, 2022-11-23:
Just disconnect it

Closed 2022-11-23.

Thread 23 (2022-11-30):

Yeah, it's me again...

Liight07, 2022-11-30:
Hello, it's me again...

I'm sorry to be such a trash newbie with all 3D Stuff but after 2 days of searching, testing and destroying my SR leveling switch, I can't stay without a solution.
Since the update, I can't make a simple Z Calibration. The "Probe" one just go down and finally crashed and broke my leveling sensor... I did the Restoration to the standard Klipper firmware on my SpeedPad, but I have the same results
Think I tried everything I could with my knowledge and some tutorials on Youtube and Klipper Documentation [https://www.klipper3d.org/Probe_Calibrate.html]. The macro SET GCODE OFFSET don't do anything unless the error message "Unable to save variable"

So if someone care about me and my issue I'll be glad... 😄

I tried to figure out what I did wrong but I haven't any idea. Thanks your time, support and kindness
[moonraker-1.log](https://github.com/Guilouz/Klipper-Flsun-Speeder-Pad/files/10126571/moonraker-1.log)
[klippy-1 (1).log](https://github.com/Guilouz/Klipper-Flsun-Speeder-Pad/files/10126572/klippy-1.1.log)

Guilouz, 2022-12-09:
No support for this kind of issue of Klipper here. Use Issues tab only to report issue for the content of this git.

Closed 2022-12-09.

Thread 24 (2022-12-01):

Error on last step converting the firmware to update the V400

tokamac, 2022-12-01:
After the following step which completes successfully (after all previous successful steps):
```
pi@speeder-pad:~/klipper$ make
  Creating symbolic link out/board
  Building out/autoconf.h
  Compiling out/src/sched.o
  Compiling out/src/command.o
  Compiling out/src/basecmd.o
  Compiling out/src/debugcmds.o
  Compiling out/src/initial_pins.o
  Compiling out/src/gpiocmds.o
  Compiling out/src/stepper.o
  Compiling out/src/endstop.o
  Compiling out/src/trsync.o
  Compiling out/src/adccmds.o
  Compiling out/src/spicmds.o
  Compiling out/src/thermocouple.o
  Compiling out/src/i2ccmds.o
  Compiling out/src/pwmcmds.o
  Compiling out/src/spi_software.o
  Compiling out/src/sensor_adxl345.o
  Compiling out/src/sensor_angle.o
  Compiling out/src/sensor_mpu9250.o
  Compiling out/src/lcd_st7920.o
  Compiling out/src/lcd_hd44780.o
  Compiling out/src/buttons.o
  Compiling out/src/tmcuart.o
  Compiling out/src/neopixel.o
  Compiling out/src/pulse_counter.o
  Compiling out/src/avr/main.o
  Compiling out/src/avr/timer.o
  Compiling out/src/avr/gpio.o
  Compiling out/src/avr/adc.o
  Compiling out/src/avr/spi.o
  Compiling out/src/avr/i2c.o
  Compiling out/src/avr/hard_pwm.o
  Compiling out/src/avr/watchdog.o
  Compiling out/src/avr/serial.o
  Compiling out/src/generic/serial_irq.o
  Building out/compile_time_request.o
Version: v0.11.0-0-ge02b7256
  Linking out/klipper.elf
  Creating hex file out/klipper.elf.hex
```
Th step converting the firmware fails:
```
pi@speeder-pad:~/klipper$ ./scripts/update_mks_robin.py out/klipper.bin out/Robin_nano35.bin
Traceback (most recent call last):
  File "./scripts/update_mks_robin.py", line 38, in <module>
    main()
  File "./scripts/update_mks_robin.py", line 25, in main
    f = open(infilename, "rb")
IOError: [Errno 2] No such file or directory: 'out/klipper.bin'
```

Guilouz, 2022-12-01:
You have not selected correct firmware config.
You obtain a hex file and not a bin file.

tokamac, 2022-12-02:
I think I see where I made my mistake: I've just selected "Enable extra low-level configuration options" without touching the other subsettings like micro-controller, etc.
Will check and come back to close the issue.

tokamac, 2022-12-02:
That was it! Incorrect options selected at the step `make menuconfig`
Problem solved.
I close the (non)issue.

Closed 2022-12-01.

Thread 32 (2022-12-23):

Problème connexion wifi

Flazor-sun, 2022-12-23:
Bonjour,

Je me permets de vous contacter car j'ai fait la mise à niveau de mon imprimante V400. Tout c'est bien passé.
Sauf que j'ai voulu la changer de wifi (après m-à-j) est la, impossible de la connecter au réseau voulu, j'ai le message Attempting to connect to (SSID).
J'ai donc supprimer le réseau sur lequel je voulais la connecter en laissant l'ancien, puis redémarré. Elle ne se reconnecte même pas à l'ancien.
Alors j'ai essayé de supprimer l'ancien et reconnecté, toujours pareil j'ai le même défaut qu'expliqué ci-dessus (attempting).
Cela serait-il dû modification de l'emplacement wifi?

Merci d'avance

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

Guilouz, 2022-12-23:
Problème non lié au github. Pour la prochaine fois merci de ne reporter que les problème lié au contenu du github.

La partie wifi de l'OS du pad est vraiment merdique. Quelqu'un qui a changé de box a eu le même tour, il a dû réinstaller le pad.

Flazor-sun, 2022-12-23:
Très bien c'est noté, merci de la rapidité.
Bonnes fêtes ;)

Closed 2022-12-23.

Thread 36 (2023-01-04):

SD card formating

phnxdrgn536, 2023-01-04:
in the guide you should put a warning at the top to make sure your SD card is not only formatted in FAT32, but that the partition is a PRIMARY partition and not a data partition... any time i used windows quick format to format the card to FAT32 it would format the partition as a data partition and i spent hours worried i bricked my printer cause the motherboard wouldn't install the new firmware off the SD card

flasher69, 2023-01-08:
True! I had the same issue. I used another SD-card and that worked. How do you format a SD-card with only Primary anyway?

Closed 2023-01-17.

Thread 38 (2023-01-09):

START_PRINT macro extruder temp logic check

ssumichrast, 2023-01-09:
https://github.com/Guilouz/Klipper-Flsun-Speeder-Pad/blob/7bae84e4eb0e38c0854a6cb8b7aef0aa4ec63d1d/Configurations/FLSUN%20V400/MKS%20Robin%20Nano%202.0%20-%20Stock/m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

Good evening. I'm not sure if this macro is working the way it should, but I'm also fairly new to understanding Klipper.

As I understand it (from this sample code: https://github.com/LuciusDante/Klipper/blob/main/macros.cfg ), `printer.exturder.target` should be set to the setpoint for the extruder. At the point line 22 is run there's no extruder heater temp target set, to my understanding -- but line 23 would set that.

I think line 22 and 24-26 are unnecessary. Line 17 is checking if an extruder temp was passed via parameter to the `START_PRINT` macro, and if not assign it to 210. Either way by the time we call `M104` to set the extruder temp we will either have the setpoint called by the slicer, or default to 210. So I'm not sure what the point of the check is.

This is delaying my print jobs because when I send the file and line 22 if statement is checked there's no target, and it's setting my printer to 150 degrees instead of using the setpoint that was called by the slicer. So if I preheat my printer to 210, for example, this is causing it to cool down to 150, and then begin the prints.

Am I misunderstanding this? Happy to submit a PR with the changes if you agree.

Guilouz, 2023-01-09:
My start macro has 2 options:
- If the hotend and the bed have been preheated before the launch of the print:

 The temperatures then directly take the values   defined in the slicer.

 - If the hotend and the bed are not preheated before the launch of the print:

 The hotend is then heated to 150C while waiting for the bed to take its set temperature. This prevents the nozzle from heating up with filament without printing because the bed takes much longer to heat up

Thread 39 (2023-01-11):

Neopixel in MKS Robin Nano v2.0 for Flsun v400

Kortivex, 2023-01-11:
Hello @Guilouz, I have all the materials and I have made a direct connection to the port that appears in the instructions for that board as well as adding the settings and the menu as indicated but they do not turn on, do you know what it could be or details that I have overlooked? ?

Guilouz, 2023-01-17:
No user support here. Thanks.

Closed 2023-01-17.

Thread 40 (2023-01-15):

Shutdown reboots the system, when using Mainsail, works fine via Klipper Screen

Dark-Noir, 2023-01-15:
Hey,

thanks for the guide, nice work but i got a problem.

It reboots on the shutdown command via the web interface, but it seems to work fine directly via the pad.

I saw your issue report at the [moonraker repo](https://github.com/Arksine/moonraker/issues/546), but i don't get why it works via the pad directly.

A fix would be nice ^^

Edit: Seems to be something weird with the OS:

- sudo shutdown now
- sudo shutdown -P now
- sudo shutdown -h 0
- sudo shutdown -h -P now
- sudo poweroff

entered in the SSH console also reboots the system, but this shouldn't happen.
I wonder which command KlipperScreen sends, because as is said, directly via the pad it works.

Edit2: I checked your KlipperScreen repo and found out that the pad uses: "shutdown -H now" and that seems to work, even without sudo (the console throws an error, without it, but it works).

How we get mainsail/moonraker to use this command?

Closed 2023-01-17.

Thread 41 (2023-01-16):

Speeder pad Moonraker issue

abhishekgyani, 2023-01-16:
Hi,I tried restarting the firmware and i was able to print a model and then afterwards im unable to connect to printer and its showing moonraker connection issue, moonraker might have been wrongly parsed error. the printer is showing disconnecting. can you help me out?
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

Guilouz, 2023-01-17:
No user support here. Thanks.

Closed 2023-01-17.

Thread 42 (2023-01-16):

Tailscale gets reinstalled bricking wifi

andrewcharnley, 2023-01-16:
Unsure how it happened but at some point after enabling the klipperscreen auto update this package was reinstalled. Wifi won't connect now.

Add a rule to apt to block the package.

sudo apt-mark hold tailscale

Guilouz, 2023-01-17:
No issue for me I can update tailscale without issue.

andrewcharnley, 2023-01-18:
Problem solved then, your guide says to remove it then it gets automatically installed later on and bricks the wifi. No issue.

Closed 2023-01-17.

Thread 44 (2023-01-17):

USB ADXL345 Triangle Lab

JSI33, 2023-01-17:
Hello. I have seen that you make an STL to put an USB ADXL345 TriangleLab on a V400. But on your github you don't explain how to configure this adxl and i trying to flash it with the TriangleLab instructions but it fail when i try to flash it. Can you help me please?

Thanks

JSI33

Guilouz, 2023-01-17:
It's explain...

https://github.com/Guilouz/Klipper-Flsun-Speeder-Pad#use-adxl345-with-fysetc-portable-input-shaper

JSI33, 2023-01-18:
Thanks for your answer. Yes bute the TriangleLab adxl345 have two buttons. The manipulation seems to be different.
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

Guilouz, 2023-01-18:
Ah sorry i didn’t see it’s a triangle lab.

Check trianglelab documentation for that: https://drive.google.com/drive/mobile/folders/1lXzN1LilcKusdOj9-mwBFJ6B84XiJpRR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

JSI33, 2023-01-18:
Done! But i will be missing somthing cause it didn't work.

Guilouz, 2023-01-18:
I didn’t have it so i can’t help you, sorry.

Closed 2023-01-17.

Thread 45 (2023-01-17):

% symbol missing from Speeder-Pad

JustTheDazz, 2023-01-17:
Trying to connect to my network and I cannot see the % symbol anywhere?

Guilouz, 2023-01-17:
It's related to KlipperScreen.

Closed 2023-01-17.

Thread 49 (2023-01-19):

Wifi breaking

Warren73, 2023-01-19:
So I've had this happen twice now. I've gone through the process and rooted and everything seems to be functioning normal but then wifi breaks and gets set to eth0. It still shows the wifi connections and even says it's connected, but it will not work over wifi nor does it actually get an ip address so I can't ssh into it. I believe it happens when I used the emergency stop red button on the speeder pad but can't say for sure as I haven't tested it out repeatedly.

Not sure if there's a fix since there's no network access and I can't ssh into it nor is there a command line I can access from the pad itself. The only console on there does macros only from what I can tell.

I'm going to reload it again this morning and I might try to recreate this just to verify. But it's happened twice now and I'm strongly considering ditching this lame ass speeder pad and just installing something else to be the controller.

Warren73, 2023-01-20:
Just a follow up, reinstalled from the image and went through the process again. At about three different times in the process I did an emergency stop but it did not switch to eth0 again. Such a weird error, really wish I could solder better so I could put an actual ethernet port on this thing.

phnxdrgn536, 2023-01-20:
Do you think a USB to ethernet adapter would work? Wonder if the speeder
pad would recognize it…

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

Guilouz, 2023-01-20:
Please don't use pull request for support.It's only to report an issue on github.

Closed 2023-01-20.

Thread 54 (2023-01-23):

Printer not accepting firmware

Yeetographer, 2023-01-23:
I have verified that I am performing the steps to update the motherboard firmware correctly, and when I insert the SD card into the printer, the FLSUN logo flashes for a few seconds, and then stays solid. I turn off the printer, insert the SD card into my computer, and the file is indeed renamed to a .cur file, but the printer will not connect to klipper anymore. I have redone it multiple times to make sure it wasn't a mess up, but it will not work no matter what I've tried. I've tried different SD cards as well.

Yeetographer, 2023-01-23:
here are the lines from MobaXterm:
pi@speeder-pad:~$ cd ~/klipper/
pi@speeder-pad:~/klipper$ make menuconfig
Loaded configuration '/home/pi/klipper/.config'
No changes to save (for '/home/pi/klipper/.config')
pi@speeder-pad:~/klipper$ make clean
pi@speeder-pad:~/klipper$ make
  Creating symbolic link out/board
  Building out/autoconf.h
  Compiling out/src/sched.o
  Compiling out/src/command.o
  Compiling out/src/basecmd.o
  Compiling out/src/debugcmds.o
  Compiling out/src/initial_pins.o
  Compiling out/src/gpiocmds.o
  Compiling out/src/stepper.o
  Compiling out/src/endstop.o
  Compiling out/src/trsync.o
  Compiling out/src/adccmds.o
  Compiling out/src/spicmds.o
  Compiling out/src/thermocouple.o
  Compiling out/src/i2ccmds.o
  Compiling out/src/pwmcmds.o
  Compiling out/src/spi_software.o
  Compiling out/src/sensor_adxl345.o
  Compiling out/src/sensor_angle.o
  Compiling out/src/sensor_mpu9250.o
  Compiling out/src/lcd_st7920.o
  Compiling out/src/lcd_hd44780.o
  Compiling out/src/buttons.o
  Compiling out/src/tmcuart.o
  Compiling out/src/neopixel.o
  Compiling out/src/pulse_counter.o
  Compiling out/src/stm32/watchdog.o
  Compiling out/src/stm32/gpio.o
  Compiling out/src/stm32/clockline.o
  Compiling out/src/stm32/dfu_reboot.o
  Compiling out/src/generic/crc16_ccitt.o
  Compiling out/src/generic/armcm_boot.o
  Compiling out/src/generic/armcm_irq.o
  Compiling out/src/generic/armcm_reset.o
  Compiling out/src/../lib/stm32f1/system_stm32f1xx.o
  Compiling out/src/stm32/stm32f1.o
  Compiling out/src/generic/armcm_timer.o
  Compiling out/src/stm32/adc.o
  Compiling out/src/stm32/i2c.o
  Compiling out/src/stm32/spi.o
  Compiling out/src/stm32/serial.o
  Compiling out/src/generic/serial_irq.o
  Compiling out/src/stm32/hard_pwm.o
  Building out/compile_time_request.o
Version: v0.11.0-86-g6026a99a
  Preprocessing out/src/generic/armcm_link.ld
  Linking out/klipper.elf
  Creating hex file out/klipper.bin
pi@speeder-pad:~/klipper$ ./scripts/update_mks_robin.py out/klipper.bin out/Robin_nano35.bin
pi@speeder-pad:~/klipper$

Yeetographer, 2023-01-23:
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

Yeetographer, 2023-01-23:
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

Yeetographer, 2023-01-23:
Discovered that I made a typo in the printer.cfg file for the USB connection. Issue was unrelated to all screenshots.

Closed 2023-01-23.

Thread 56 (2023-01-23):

Unable to recovery klipper

itajackass, 2023-01-23:
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

Today, Every time i poweron speeder pad i get INVALID klipper message. I tried hard and soft recovery without success... It work about 10 minutes on this screen (see pic), then fail.

itajackass, 2023-01-24:
after some retry i get klipper valid again. before this problem I've assigned fixed IP of speederpad into my network to 192.168.1.102........now when i power on speederpad I see into my network 2 different devices with same name SPEEDERPAD and 2 different MAC ADDRESS and of course 2 different IP.....192.168.1.102 (fixed ip...but not reachable)....and 192.168.1.106 (dhcp....working)......Why?

Guilouz, 2023-01-25:
No support here. Please only post issues related to github.

Closed 2023-01-25.

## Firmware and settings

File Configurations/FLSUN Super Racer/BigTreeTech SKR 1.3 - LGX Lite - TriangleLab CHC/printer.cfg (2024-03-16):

#   _____             __ _                       _   _                
#  / ____|           / _(_)                     | | (_)                
# | |     ___  _ __ | |_ _  __ _ _   _ _ __ __ _| |_ _  ___  _ __  ___ 
# | |    / _ \| '_ \|  _| |/ _` | | | | '__/ _` | __| |/ _ \| '_ \/ __|
# | |___| (_) | | | | | | | (_| | |_| | | | (_| | |_| | (_) | | | \__ \
#  \_____\___/|_| |_|_| |_|\__, |\__,_|_|  \__,_|\__|_|\___/|_| |_|___/
#                           __/ |                                      
#                          |___/    
#
# Klipper Configurations - Flsun Super Racer
# Version 3.0
#
# Guislain Cyril


########################################
# Firmware Settings
########################################

# BigTreeTech SKR 1.3
# BondTech LGX Lite
# TriangleLab CHC Pro

# When running "make menuconfig"
#
# [*] Enable extra low-level configuration options
#     Micro-controller Architecture (LPC176x (Smoothieboard))  --->
#     Processor model (lpc1768 (100 MHz))  --->
#     Bootloader offset (16KiB bootloader (Smoothieware bootloader))  --->
#     Communication interface (USB)  --->
#     USB ids  --->
# ()  GPIO pins to set at micro-controller startup (NEW)
#
# Note that the "make flash" command does not work with this board.
# Rename the file out/klipper.bin to firmware.bin, copy it an microSD 
# card, insert it in the printer and restart it.


########################################
# Editable Settings
########################################

# Notes: Some settings can be enabled or disabled by removing or adding the '#' symbol
#
# PID (pid_Kp, pid_Ki, pid_Kd) --> [extruder] and [heater_bed] sections
# E-Steps Extruder (rotation_distance) --> [extruder] section --> <rotation_distance> = <full_steps_per_rotation> * <microsteps> / <steps_per_mm>
# Pressure Advance (pressure_advance) --> [extruder] section -- See: https://www.klipper3d.org/Pressure_Advance.html
# Firmware Retraction --> [firmware_retraction] section -- Requires "Klipper Settings Plugin" for Cura -- See: https://github.com/jjgraphix/KlipperSettingsPlugin
# ADXL345 function for resonance testing --> Enable/Disable [include adxl345_pico.cfg] or [include adxl345_fysetc.cfg] -- Configuration in [input_shaper] section -- See: https://www.klipper3d.org/Measuring_Resonances.html
# NeoPixels macros --> Enable/Disable [include neopixels.cfg]
# Timelapse function --> Enable/Disable [include timelapse.cfg]


########################################
# Included Files
########################################

[include macros.cfg]
#[include adxl345_pico.cfg]  #Enable if you want to use ADXL with Rapsberry Pi Pico
#[include adxl345_fysetc.cfg]  #Enable if you want to use ADXL with Fysetc Portable Input Shaper
#[include timelapse.cfg]  #Enable if you want to use Timelapse
#[include neopixels.cfg]  #Enable if you want to use some Neopixels macros


########################################
# Printer Settings
########################################

[printer]
kinematics: delta
max_velocity: 300
max_accel: 4000
minimum_cruise_ratio: 0.5
square_corner_velocity: 5
max_z_velocity: 100
max_z_accel: 1500
minimum_z_position: -25
print_radius: 132
delta_radius: 151.7


########################################
# X Stepper Motor & Driver Settings
########################################

[stepper_a]
step_pin: P2.2
dir_pin: P2.6
enable_pin: !P2.1
microsteps: 16
rotation_distance: 40
endstop_pin: P1.28
homing_speed: 50
homing_retract_dist: 5.0
homing_retract_speed: 10
angle: 210
position_endstop: 336
arm_length = 315

[tmc2209 stepper_a]
uart_pin: P1.17
run_current: 1.138
hold_current: 0.5
stealthchop_threshold: 999999


########################################
# Y Stepper Motor & Driver Settings
########################################

[stepper_b]
step_pin: P0.19
dir_pin: P0.20
enable_pin: !P2.8
microsteps: 16
rotation_distance: 40
endstop_pin: P1.26
angle: 330

[tmc2209 stepper_b]
uart_pin: P1.15
run_current: 1.138
hold_current: 0.5
stealthchop_threshold: 999999


########################################
# Z Stepper Motor & Driver Settings
########################################

[stepper_c]
step_pin: P0.22
dir_pin: P2.11
enable_pin: !P0.21
microsteps: 16
rotation_distance: 40
endstop_pin: P1.24
angle: 90

[tmc2209 stepper_c]
uart_pin: P1.10
run_current: 1.138
hold_current: 0.5
stealthchop_threshold: 999999


########################################
# Extruder & Driver Settings
########################################

[extruder]
step_pin: P2.13
dir_pin: P0.11
enable_pin: !P2.12
microsteps: 16
rotation_distance: 5.7
full_steps_per_rotation: 200
nozzle_diameter: 0.4
filament_diameter: 1.750
heater_pin: P2.7
sensor_type: ATC Semitec 104NT-4-R025H42G
sensor_pin: P0.24
min_temp: -5
max_temp: 275
max_extrude_only_distance: 800.0
max_extrude_only_velocity: 120
max_extrude_only_accel: 800
instantaneous_corner_velocity: 2.5
#pressure_advance: 0.04
#pressure_advance_smooth_time: 0.01
control = pid
pid_kp = 18.240
pid_ki = 0.558
pid_kd = 149.109

[tmc2209 extruder]
uart_pin: P1.8
run_current: 0.7
hold_current: 0.5
stealthchop_threshold: 999999


########################################
# Bed Settings
########################################

[heater_bed]
heater_pin: P2.5
sensor_type: EPCOS 100K B57560G104F
sensor_pin: P0.23
min_temp: -5
max_temp: 115
control = pid
pid_kp = 71.041
pid_ki = 1.422
pid_kd = 887.123


########################################
# Filament Sensor Settings
########################################

[filament_switch_sensor filament_sensor]
pause_on_runout: True
runout_gcode: M600
switch_pin: P1.29


########################################
# Fans Settings
########################################

[fan]
pin: P2.3

[heater_fan Hotend]
pin: P2.4
heater_temp: 50.0


########################################
# Probe Settings
########################################

[probe]
pin: !P1.25
x_offset: 0
y_offset: 0
z_offset: 0
speed: 10
lift_speed: 50
samples: 3
samples_result: average
sample_retract_dist: 6
samples_tolerance: 0.02
samples_tolerance_retries: 5


########################################
# Delta Calibration & Mesh Settings
########################################

[delta_calibrate]
radius: 130
horizontal_move_z: 30
speed: 100

[bed_mesh]
speed: 100
horizontal_move_z: 30
mesh_radius: 130
mesh_origin: 0,0
mesh_pps: 4,4
round_probe_count: 9
algorithm: bicubic
bicubic_tension: 0.1
move_check_distance: 3
#fade_start: 1
#fade_end: 30


########################################
# Temperature Controls
########################################

[verify_heater extruder]
max_error: 160
heating_gain: 1

[verify_heater heater_bed]
max_error: 120
heating_gain: 1


########################################
# Firmware Retraction Settings
########################################

[firmware_retraction]
retract_length: 1.2
retract_speed: 35
unretract_extra_length: 0.05
unretract_speed: 35


########################################
# Input Shaper Settings
########################################

[input_shaper]
shaper_freq_x: 25.00
shaper_type_x = mzv
shaper_freq_y: 23.29
shaper_type_y = mzv


########################################
# G-Code Macros & Events
########################################

[idle_timeout]
timeout: 1800

[save_variables]
filename: ~/printer_data/config/variables.cfg

[gcode_arcs]
resolution: 0.1

[pause_resume]

[display_status]

[respond]

[exclude_object]

[virtual_sdcard]
path: ~/printer_data/gcodes

[endstop_phase stepper_a]
endstop_align_zero: false

[endstop_phase stepper_b]
endstop_align_zero: false

[endstop_phase stepper_c]
endstop_align_zero: false 


########################################
# MCU Settings
########################################

[mcu]
serial: XXXXX
restart_method: command

[temperature_sensor Speeder_Pad]
sensor_type: temperature_host
min_temp: 10
max_temp: 100


########################################
# LED Settings
########################################

#[neopixel NeoPixels]
#pin: P1.27
#chain_count: 34
#color_order: GRB
#initial_RED: 1.0
#initial_GREEN: 1.0
#initial_BLUE: 1.0

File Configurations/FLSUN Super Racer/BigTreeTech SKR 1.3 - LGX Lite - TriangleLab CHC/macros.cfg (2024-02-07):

#  __  __                          
# |  \/  |                         
# | \  / | __ _  ___ _ __ ___  ___ 
# | |\/| |/ _` |/ __| '__/ _ \/ __|
# | |  | | (_| | (__| | | (_) \__ \
# |_|  |_|\__,_|\___|_|  \___/|___/
#
# Macros Configurations - Flsun Super Racer
# Version 3.0
#
# Guislain Cyril


##################################################
# Start and End G-Codes
##################################################

[gcode_macro START_PRINT]
description: Start G-Code
gcode:
  {% set BED_TEMP = params.BED_TEMP|default(60)|float %}
  {% set EXTRUDER_TEMP = params.EXTRUDER_TEMP|default(210)|float %}
  G21
  G90
  M82
  {% if printer.extruder.target != 0 %}
  M104 S{EXTRUDER_TEMP}
  {% else %}
  M104 S150
  {% endif %}
  M140 S{BED_TEMP}
  {% if printer.toolhead.homed_axes != "xyz" %}
  G28
  {% endif %}
  G1 Z270 F2500
  G1 X-130 F2500
  M190 S{BED_TEMP}
  M109 S{EXTRUDER_TEMP}
  G1 Z1 F2500
  G1 X-130 Y0 Z0.4
  G92 E0
  G3 X0 Y-130 I130 J1 Z0.3 E40 F1500
  G92 E0
  G1 E-1.5 F1800


[gcode_macro END_PRINT]
description: End G-Code
gcode:
  M106 S0
  M104 S0
  M140 S0
  G92 E0
  G91
  G1 E-1 F300
  G1 Z+5 F6000
  G28
  G90
  M84


##################################################
# Pause / Resume / Cancel Print
##################################################

[gcode_macro PAUSE]
description: Pause the current print
rename_existing: PAUSE_BASE
gcode:
  ##### set defaults #####
  {% set x = params.X|default(0) %}
  {% set y = params.Y|default(-122) %}
  {% set z = params.Z|default(10)|float %}
  {% set e = params.E|default(1) %}
  ##### calculate save lift position #####
  {% set max_z = printer.toolhead.axis_maximum.z|float %}
  {% set act_z = printer.toolhead.position.z|float %}
  {% set lift_z = z|abs %}
  {% if act_z < (max_z - lift_z) %}
  {% set z_safe = lift_z %}
  {% else %}
  {% set z_safe = max_z - act_z %}
  {% endif %}
  ##### end of definitions #####
  RESPOND MSG="Pausing printing..."
  PAUSE_BASE
  G91
  G1 E-{e} F2100
  G1 Z{z_safe} F900
  G90
  G1 X{x} Y{y} F2500


[gcode_macro RESUME]
description: Resume the current print
rename_existing: RESUME_BASE
gcode:
  ##### set defaults #####
  {% set e = params.E|default(1) %}
  #### get VELOCITY parameter if specified ####
  {% if 'VELOCITY' in params|upper %}
  {% set get_params = ('VELOCITY=' + params.VELOCITY)  %}
  {% else %}
  {% set get_params = "" %}
  {% endif %}
  ##### end of definitions #####
  G91
  {% if printer["gcode_macro M600"].m600_enabled == 1 %}
  RESPOND MSG="Nozzle heating..."
  M109 S{printer["gcode_macro M600"].hotend_temp}
  M106 S{printer["gcode_macro M600"].fan_speed}
  RESPOND MSG="Loading filament..."
  G0 E70 F800
  G0 E20 F300
  M400
  SET_GCODE_VARIABLE MACRO=M600 VARIABLE=m600_enabled VALUE=0
  {% else %}
  G1 E{e} F2100
  {% endif %}
  RESPOND MSG="Resuming printing..."
  SET_IDLE_TIMEOUT TIMEOUT=1800
  RESUME_BASE {get_params}


[gcode_macro CANCEL_PRINT]
description: Cancel the current print
rename_existing: CANCEL_PRINT_BASE
gcode:
  RESPOND MSG="Printing canceled!"
  G28
  M106 S0
  M104 S0
  M140 S0
  CANCEL_PRINT_BASE


##################################################
# Filament / Color Change
##################################################

[gcode_macro M600]
description: Filament change
variable_hotend_temp: 0
variable_m600_enabled: 0
variable_fan_speed: 0
gcode:
  ##### set defaults #####
  {% set x = params.X|default(0) %}
  {% set y = params.Y|default(-122) %}
  {% set z = params.Z|default(10)|float %}
  {% set e = params.E|default(1) %}
  ##### calculate save lift position #####
  {% set max_z = printer.toolhead.axis_maximum.z|float %}
  {% set act_z = printer.toolhead.position.z|float %}
  {% set lift_z = z|abs %}
  {% if act_z < (max_z - lift_z) %}
  {% set z_safe = lift_z %}
  {% else %}
  {% set z_safe = max_z - act_z %}
  {% endif %}
  ##### end of definitions #####
  SAVE_GCODE_STATE NAME=M600_state
  SET_IDLE_TIMEOUT TIMEOUT=86400
  SET_GCODE_VARIABLE MACRO=M600 VARIABLE=m600_enabled VALUE=1
  SET_GCODE_VARIABLE MACRO=M600 VARIABLE=hotend_temp VALUE={printer.extruder.target}
  SET_GCODE_VARIABLE MACRO=M600 VARIABLE=fan_speed VALUE={printer.fan.speed}
  RESPOND MSG="Pausing printing..."
  PAUSE
  G91
  G1 E-{e} F2100
  G1 Z{z_safe}
  G90
  G1 X{x} Y{y} F2500
  RESPOND MSG="Unloading filament..."
  G91
  G0 E-5 F300
  G0 E-70 F800
  M400
  RESPOND MSG="Nozzle heating stopped!"
  M104 S0
  M106 S0
  RESTORE_GCODE_STATE NAME=M600_state


##################################################
# Load / Unload Filament
##################################################

[gcode_macro UNLOAD_FILAMENT]
description: Filament unloading
gcode:
  {% if printer.idle_timeout.state == "Printing" and not printer.pause_resume.is_paused %}
  RESPOND TYPE=error MSG="This macro cannot be used while printing!"
  {% else %}
  SAVE_GCODE_STATE NAME=unload_state
  {% if printer.extruder.temperature < 200 %}
  RESPOND MSG="Nozzle heating..."
  M109 S200
  {% endif %}
  RESPOND MSG="Unloading filament..."
  G91
  G0 E2 F400
  G0 E-5 F800
  G0 E-70 F800
  RESTORE_GCODE_STATE NAME=unload_state
  {% endif %}


[gcode_macro LOAD_FILAMENT]
description: Filament loading
gcode:
  {% if printer.idle_timeout.state == "Printing" and not printer.pause_resume.is_paused %}
  RESPOND TYPE=error MSG="This macro cannot be used while printing!"
  {% else %}
  SAVE_GCODE_STATE NAME=load_state
  {% if printer.extruder.temperature < 200 %}
  RESPOND MSG="Nozzle heating..."
  M109 S200
  {% endif %}
  RESPOND MSG="Loading filament..."
  G91
  G0 E70 F300
  G0 E20 F200
  M400
  RESTORE_GCODE_STATE NAME=load_state
  {% endif %}


##################################################
# Calibrations
##################################################

[gcode_macro Z_OFFSET_CALIBRATION]
description: Measure Z-Offset
gcode:
  SET_GCODE_OFFSET Z=0
  G28
  G1 X0 Y0 Z50 F2500
  M400
  PROBE_CALIBRATE


[gcode_macro ENDSTOPS_CALIBRATION]
description: Endstops Phase Calibration
gcode:
  {% if printer.idle_timeout.state == "Printing" %}
  RESPOND TYPE=error MSG="This macro cannot be used while printing!"
  {% else %}
  {% if printer.toolhead.homed_axes != "xyz" %}
  G28
  {% endif %}
  G91
  G0 Z-70 F1500
  G28
  G91
  G0 Z-70 F1500
  G28
  G91
  G0 Z-70 F1500
  G28
  G91
  G0 Z-70 F1500
  G28
  G91
  G0 Z-70 F1500
  ENDSTOP_PHASE_CALIBRATE stepper=stepper_a
  ENDSTOP_PHASE_CALIBRATE stepper=stepper_b
  ENDSTOP_PHASE_CALIBRATE stepper=stepper_c
  M400
  G28
  {% endif %}


[gcode_macro DELTA_CALIBRATION]
description: Delta Calibration
gcode:
  {% if printer.idle_timeout.state == "Printing" %}
  RESPOND TYPE=error MSG="This macro cannot be used while printing!"
  {% else %}
  SET_GCODE_OFFSET Z=0
  BED_MESH_CLEAR
  {% if printer.toolhead.homed_axes != "xyz" %}
  G28
  {% endif %}
  DELTA_CALIBRATE
  M400
  G1 X0 Y0 Z50 F2500
  G28
  {% endif %}


[gcode_macro BED_LEVELING]
description: Bed Leveling
gcode:
  {% if printer.idle_timeout.state == "Printing" %}
  RESPOND TYPE=error MSG="This macro cannot be used while printing!"
  {% else %}
  SET_GCODE_OFFSET Z=0
  {% if printer.toolhead.homed_axes != "xyz" %}
  G28
  {% endif %}
  G1 X0 Y0 Z50 F2500
  BED_MESH_CALIBRATE
  M400
  G1 X0 Y0 Z50 F2500
  G28
  {% endif %}


[gcode_macro PRESSURE_ADVANCE]
description: Pressure Advance
gcode:
  {% if printer.idle_timeout.state == "Printing" %}
  RESPOND TYPE=error MSG="This macro cannot be used while printing!"
  {% else %}
  SET_PRESSURE_ADVANCE ADVANCE=0   
  SET_VELOCITY_LIMIT SQUARE_CORNER_VELOCITY=1 ACCEL=500
  TUNING_TOWER COMMAND=SET_PRESSURE_ADVANCE PARAMETER=ADVANCE START=0 FACTOR=.005
  {% endif %}


##################################################
# Nozzle / Bed PID Calibration
##################################################

[gcode_macro PID_BED]
description: Bed PID
gcode:
  {% if printer.idle_timeout.state == "Printing" %}
  RESPOND TYPE=error MSG="This macro cannot be used while printing!"
  {% else %}
  RESPOND MSG="Bed PID calibration in progress..."
  G28
  G90
  G1 Z50 F1500
  M400
  M106
  PID_CALIBRATE HEATER=heater_bed TARGET={params.TEMP|default(65)}
  M107
  RESPOND MSG="PID calibration complete! Remember to save the configuration!"
  G28
  {% endif %}
  

[gcode_macro PID_HOTEND]
description: Hotend PID
gcode:
  {% if printer.idle_timeout.state == "Printing" %}
  RESPOND TYPE=error MSG="This macro cannot be used while printing!"
  {% else %}
  RESPOND MSG="Hotend PID calibration in progress..."
  G28
  G90
  G1 Z50 F1500
  M400
  M106
  PID_CALIBRATE HEATER=extruder TARGET={params.TEMP|default(220)}
  M107
  RESPOND MSG="PID calibration complete! Remember to save the configuration!"
  G28
  {% endif %}
  
  
[gcode_macro _PID_KS_START]
description: PID for KlipperScreen
gcode:
  RESPOND MSG="PID calibration in progress..."
  G28
  G90
  G1 Z50 F1500
  M400
  M106


[gcode_macro _PID_KS_END]
description: PID for KlipperScreen
gcode:
  M107
  RESPOND MSG="PID calibration complete! Remember to save the configuration!"
  G28
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

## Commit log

2022-08-29 Create V400 NanoV2 Mount.stl
    [V400 NanoV2 Mount.stl]
2022-12-11 Create FLSUN V400 - BigTreeTech SKR 3.0 Wiring.png
2023-02-15 add tips to connect multiple printers on one board
2023-02-19 Fixed "default" bed mesh in START_PRINT macro
    [macros.cfg]
2023-06-27 Update macros
    [macros.cfg]
